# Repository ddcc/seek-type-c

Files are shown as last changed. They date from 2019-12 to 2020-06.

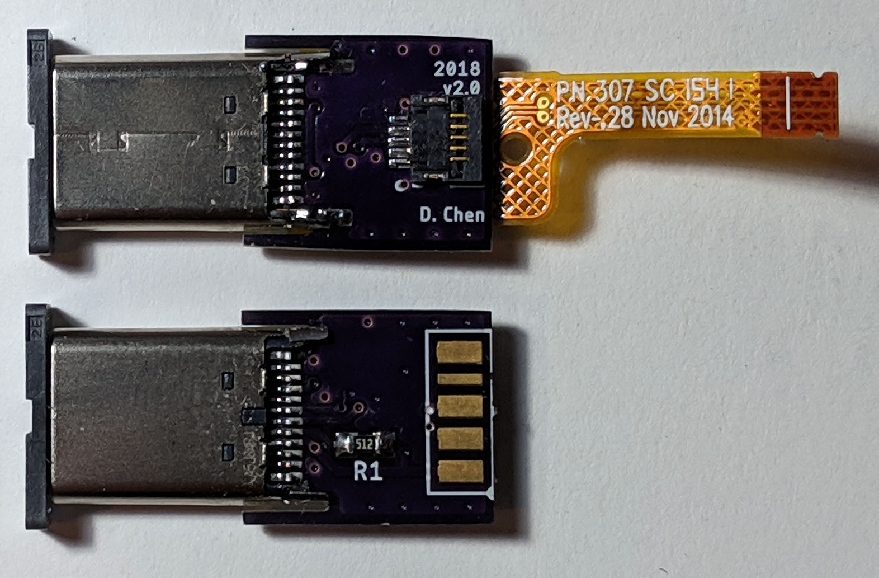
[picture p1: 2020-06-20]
photos/finalv2.board.jpg

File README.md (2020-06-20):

# Writeup

https://www.dcddcc.com/blog/2018-11-10-retrofitting-the-seek-thermal-compact-with-a-usb-type-c-connector-using-3d-printing.html

# BOM

|RefDes|Vendor|Part Number|Specs|
|---|---|---|-----|
|J1|JAE|DX07P024AJ5R1500|Straddle Mount USB 3.1 Type-C Connector|
|R1/RD|Stackpole|RMCF0603JT5K10|5.1kΩ ± 10%, 0603 (0402) for board ≤ v2.0 (≥ v2.1), or equivalent|
|J3|Seek|PN307 SC 154|FPC Adapter (option 1)|
|J2|Amphenol|59453-051110EDHLF|5-position FFC Connector, 0.5mm pitch, Right-Angle (option 2)|
|N/A|N/A|N/A|FFC Ribbon, 0.5mm pitch (option 2)|

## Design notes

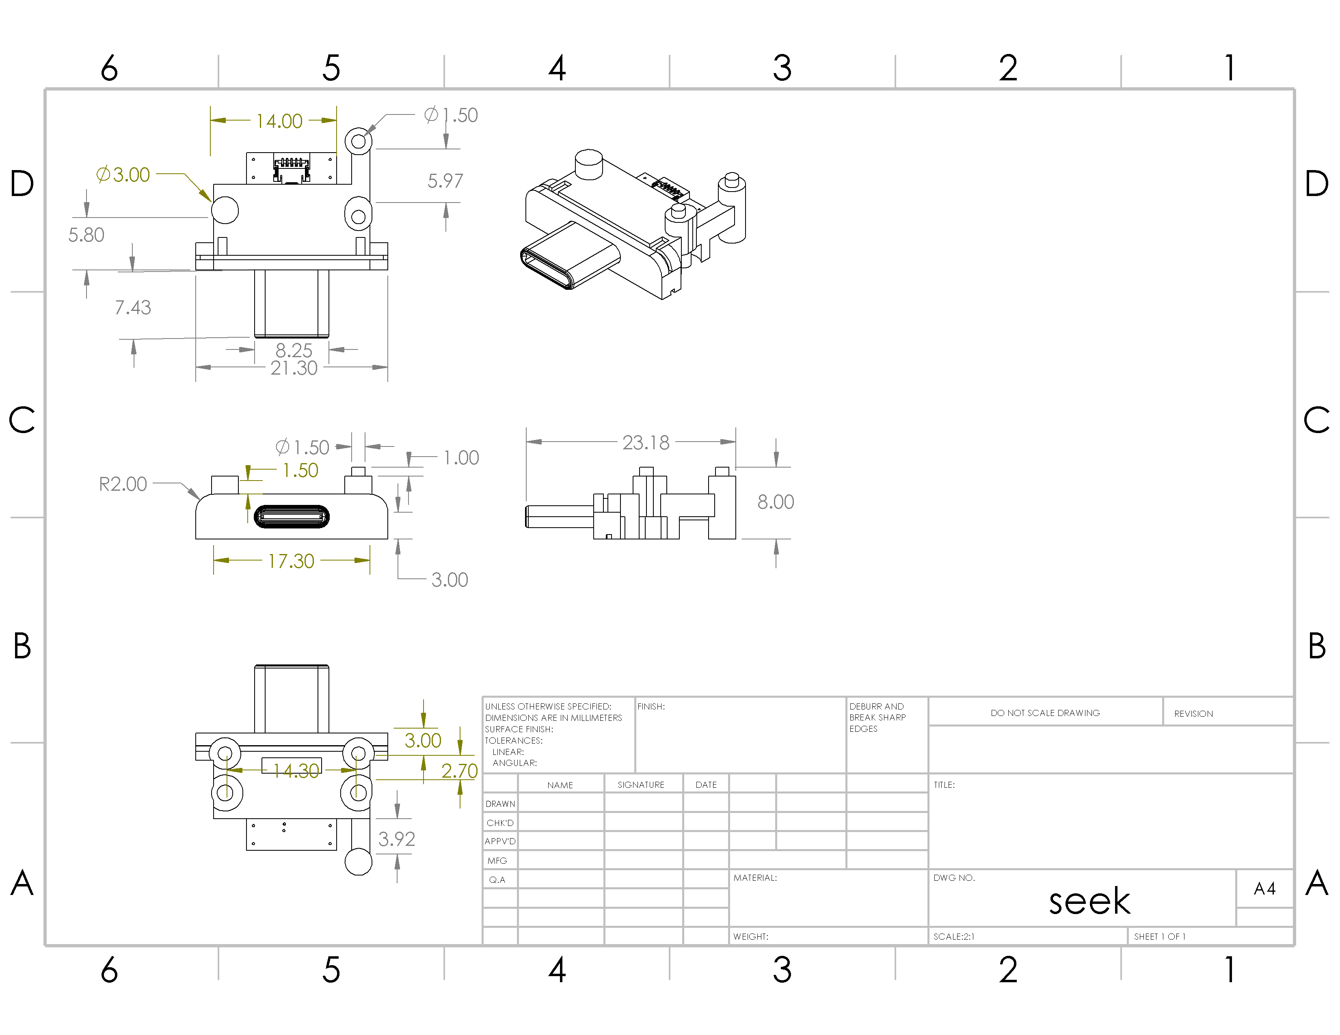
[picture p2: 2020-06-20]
models/seek.JPG

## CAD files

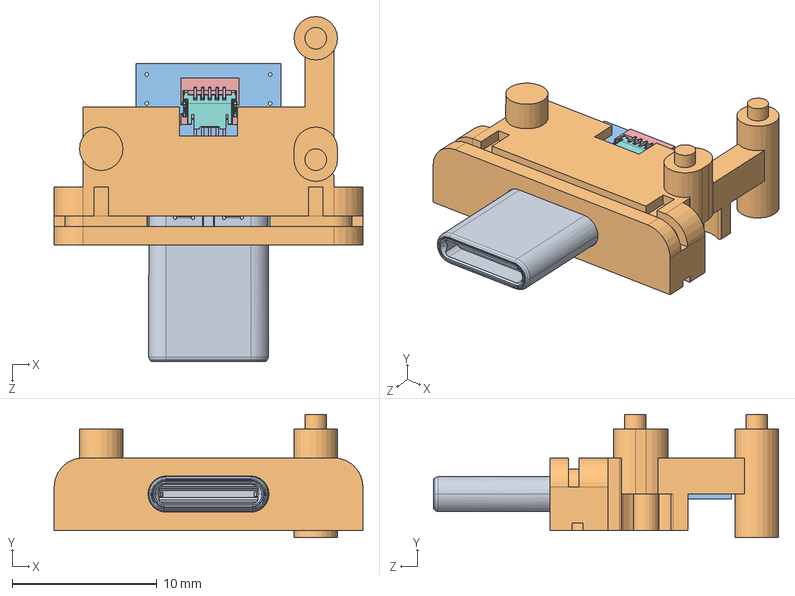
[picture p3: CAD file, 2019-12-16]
models/seek.SLDASM
21.3 x 8.50 x 23.8 mm
K3D-DX07P024AJ5-V2_JAE_Proprietary
seek
board
Resistor 0603 x 2
HSG_D5P.stp
CONTACT_D_S.stp x 5
TAB_EDLF.stp x 2
ACT_D5P.stp

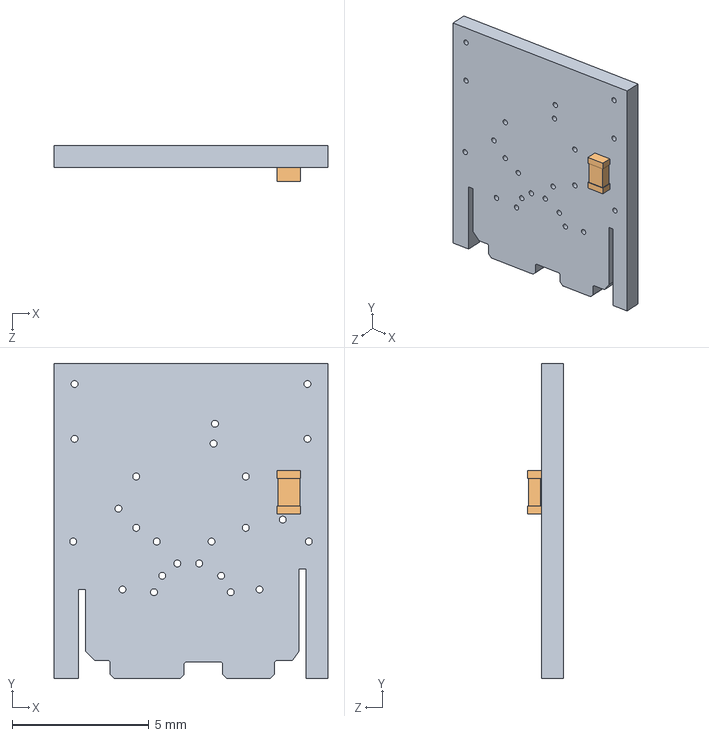
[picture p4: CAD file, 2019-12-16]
models/board.SLDASM
10.0 x 11.5 x 1.31 mm
board
Resistor 0603

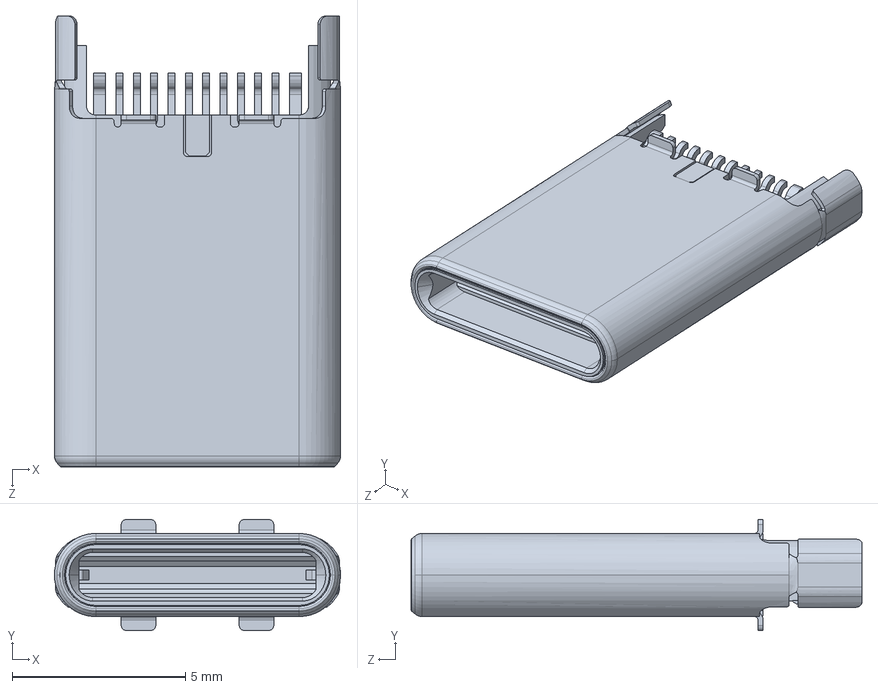
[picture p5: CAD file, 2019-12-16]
models/K3D-DX07P024AJ5-V2_JAE_Proprietary.SLDPRT
8.25 x 3.20 x 13.0 mm

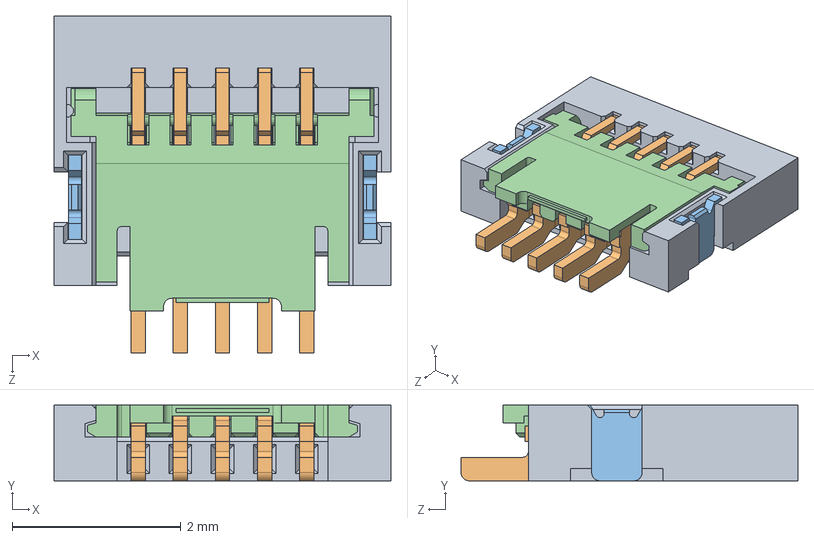
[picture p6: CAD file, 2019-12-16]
models/59453-051110edhlf.SLDASM
4.00 x 0.9 x 4.00 mm
HSG_D5P.stp
CONTACT_D_S.stp x 5
TAB_EDLF.stp x 2
ACT_D5P.stp

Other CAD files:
models/59453-051110edhlf.SLDPRT
models/board.sldprt
models/seek.SLDDRW
models/seek.SLDPRT

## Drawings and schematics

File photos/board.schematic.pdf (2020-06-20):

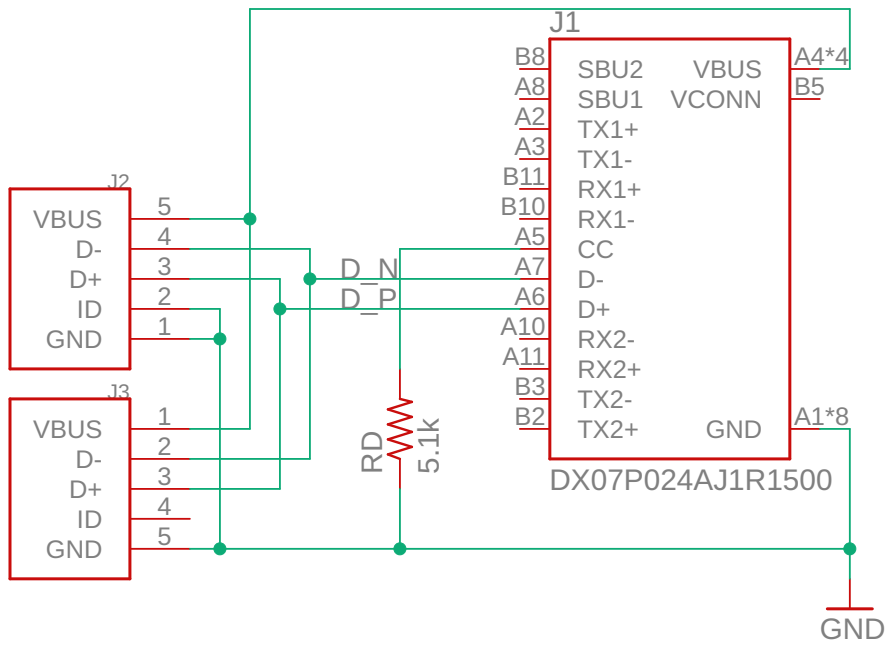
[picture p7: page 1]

5.1k DX07P024AJ1R1500GND RD TX1+ A2 TX1- A3 RX1+ B11 RX1- B10 CC A5 D- A7 D+ A6 RX2- A10 RX2+ A11 TX2- B3 TX2+ B2 VBUS A4*4 GND A1*8 SBU1 A8 VCONN B5 SBU2 B8 J1 VBUS 1 D- 2 D+ 3 ID 4 GND 5 J3 VBUS 5 D- 4 D+ 3 ID 2 GND 1 J2 D_N D_P

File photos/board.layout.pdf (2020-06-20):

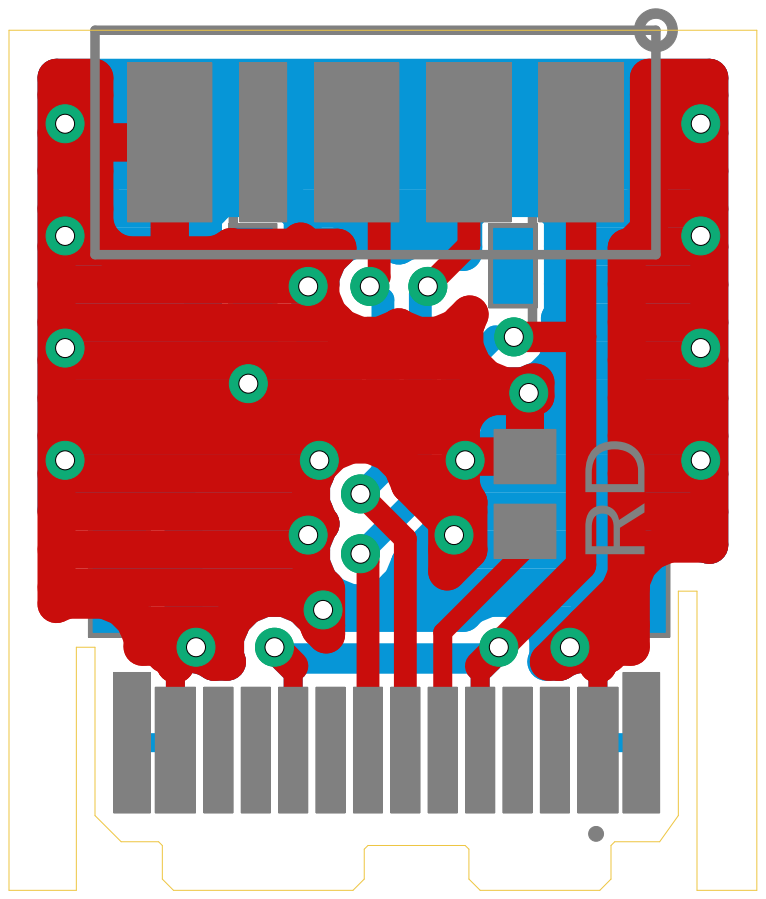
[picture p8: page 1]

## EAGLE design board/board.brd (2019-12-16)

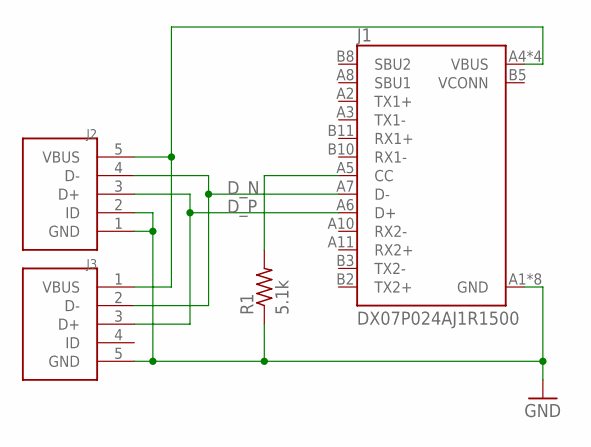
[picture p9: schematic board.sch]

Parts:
J1: DX07P024AJ1R1500; JAE_DX07P024AJ1R1500
J2: USB59453-051110EDHLF; 59453-051110EDHLF
J3: USBSEEK-USB; SEEK-USB
R1: 5.1k; R0402

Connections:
D_N: J1.A7 (D-), J2.4 (D-), J3.2 (D-)
D_P: J1.A6 (D+), J2.3 (D+), J3.3 (D+)
GND: J1.A1 (GND), J1.A12 (GND), J1.B0 (GND), J1.B1 (GND), J1.B12 (GND), J1.B13 (GND), J1.B17 (GND), J1.B18 (GND), J2.1 (GND), J2.2 (ID), J3.5 (GND), R1.1
unnamed: J1.A5 (CC), R1.2
VBUS: J1.A4 (VBUS), J1.A9 (VBUS), J1.B4 (VBUS), J1.B9 (VBUS), J2.5 (VBUS), J3.1 (VBUS)
VCONN: J1.B5 (VCONN)

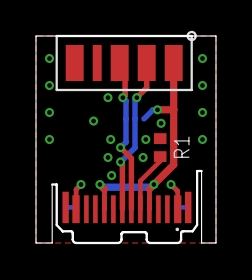
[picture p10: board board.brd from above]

Board: 2 copper layers, 10.0 x 11.5 mm, 4 parts (1 on the bottom side), 5 nets.
